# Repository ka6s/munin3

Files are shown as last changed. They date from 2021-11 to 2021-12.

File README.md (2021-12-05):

# munin3
This is a KICAD version of the Munin 3 100W amplifer designed by Kjell - LA2NI. Note that some of the DNI parts have been left out of the schematic. 

The design has been updated to the point that it reliably can balance the two transistors. Haven't verified the
Test Point for that operation yet.

Kjell, LA2NI has reviewed the design and found an error on my part when I did flooding of the power 
transformer.  Kicad didn't really do what I expected. I had to beef up these connections by hand. He also
found a couple errors in my schematic, and I found another later.. these issues have all been 
fixed.

The amplifier seems to work! 

Use the files in gerbers/munin3_v1.1.zip

Steve KA6S

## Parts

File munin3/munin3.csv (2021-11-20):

Reference | Quantity | Identifier | Package | Value | Tolerance | Voltage | Current | Power | PN | Mouser Part Number
L1 | 1 |  |  | Transformer_1P_1S
R8 | 1 |  |  | 100/1W
C8;C15 | 2 |  |  | 1nF
C6;C13;C7;C14 | 4 |  |  | 10nF
R9;R10 | 2 |  |  | 1.5K
R5;R4;R13;R15;R19;R18;R20 | 7 |  |  | 4.7
R7;R6;R12;R11 | 4 |  |  | 22 |  |  |  |  |  | 660-SG73P2ATTD220G
C4;C16 | 2 |  |  | 100pF/500V/NPO |  |  |  |  |  | 603-CC206JRNPOBBN101
L2 | 1 |  |  | Transformer-FB
C12;C11;C10 | 3 |  |  | 220pF/500V/NPO |  |  |  |  |  | 81-GRM31A5C2H221JW1D
L3 | 1 |  |  | Transformer_1P_SS
L4 | 1 |  |  | FT-50-43
C25;C30;C31 | 3 |  |  | 100nF |  |  |  |  |  | 80-C0805C104J5RAUTO
C24;C32 | 2 |  |  | 1uF |  |  |  |  |  | 667-EEE-FT1V561AP
C29;C23 | 2 |  |  | 560uF 35V |  |  |  |  |  | 661-EMZS350ARA561MJA
R23;R24 | 2 |  |  | 0.02 |  |  |  |  |  | 652-CRA2512FZ-R20ELF
U1 | 1 |  |  | MC78L08_SO8 |  |  |  |  |  | 511-L78L08ACD-TR
C35;C34 | 2 |  |  | 1uF |  |  |  |  |  | 80-C0805C104J5RAUTO
C28;C26;C2 | 3 |  |  | 10uF/35V |  |  |  |  |  | GMK316AB7106KL-TR
D6 | 1 |  |  | MBRS2545CT RN |  |  |  |  |  | 821-MBRS2545CTRN
R25 | 1 |  |  | 10K
T3 | 1 |  |  | BSS84 |  |  |  |  |  | 771-BSS84AKVL
J3;J4 | 2 |  |  | Conn_01x02_Male
D5 | 1 |  |  | 1N4001
C27 | 1 |  |  | 0.1uF
L5 | 1 |  |  | FB |  |  |  |  |  | 704-MFBM1V2012-101-R
R1;R22 | 2 |  |  | 2K |  |  |  |  |  | 81-PV12P202A01B00
R2;R21;R26 | 3 |  |  | 1K
C1;C22;C5 | 3 |  |  | 0.1uF |  |  |  |  |  | 0805DD104KAT2A
D1;D4;D2;D3 | 4 |  |  | TS4148 |  |  |  |  |  | 821-TS4148RYG
R3;R17 | 2 |  |  | 22
R16 | 1 |  |  | 3.9K
R14 | 1 |  |  | NTC 10K
C37;C33 | 2 |  |  | 0.01uF |  |  |  |  |  | 80-C0805C103K5TAUTO
R27 | 1 |  |  | 50
U2 | 1 |  |  | LMC6482
T4 | 1 |  |  | BST82 |  |  |  |  |  | 771-BST82235
J2;J1 | 2 |  |  | Conn_Coaxial
T2;T1 | 2 |  |  | Q_NMOS_DSG
H1 | 1 |  |  | +24V
H2 | 1 |  |  | GND

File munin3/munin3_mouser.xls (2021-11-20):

Reference | Quantity | Identifier | Value | Mouser Part Number
L1 | 1 |  | Transformer_1P_1S
R8 | 1 |  | 100/1W | 667-ERJ-12NF1000U
C4;C16 | 2 |  | 100pF/500V/NPO | 603-CC206JRNPOBBN101
C12;C11;C10 | 3 |  | 220pF/500V/NPO | 81-GRM31A5C2H221JW1D
C29;C23 | 2 |  | 560uF 35V | 661-EMZS350ARA561MJA
U1 | 1 |  | MC78L08_SO8 | 511-L78L08ACD-TR
C35;C34 | 2 |  | 1uF | 80-C0805C104J5RAUTO
C28;C26;C2 | 3 |  | 10uF/35V | GMK316AB7106KL-TR
D6 | 1 |  | MBRS2545CT RN | 821-MBRS2545CTRN
T3 | 1 |  | BSS84 | 771-BSS84AKVL
L5 | 1 |  | FB | 704-MFBM1V2012-101-R
R1;R22 | 2 |  | 2K | 81-PV12P202A01B00
C37;C33 | 2 |  | 0.01uF | 80-C0805C103K5TAUTO
U2 | 1 |  | LMC6482 | 511-LMC6482IST
T4 | 1 |  | BST82 | 771-BST82235
J2;J1 | 2 |  | Conn_Coaxial | 712-CONSMA001-C-G

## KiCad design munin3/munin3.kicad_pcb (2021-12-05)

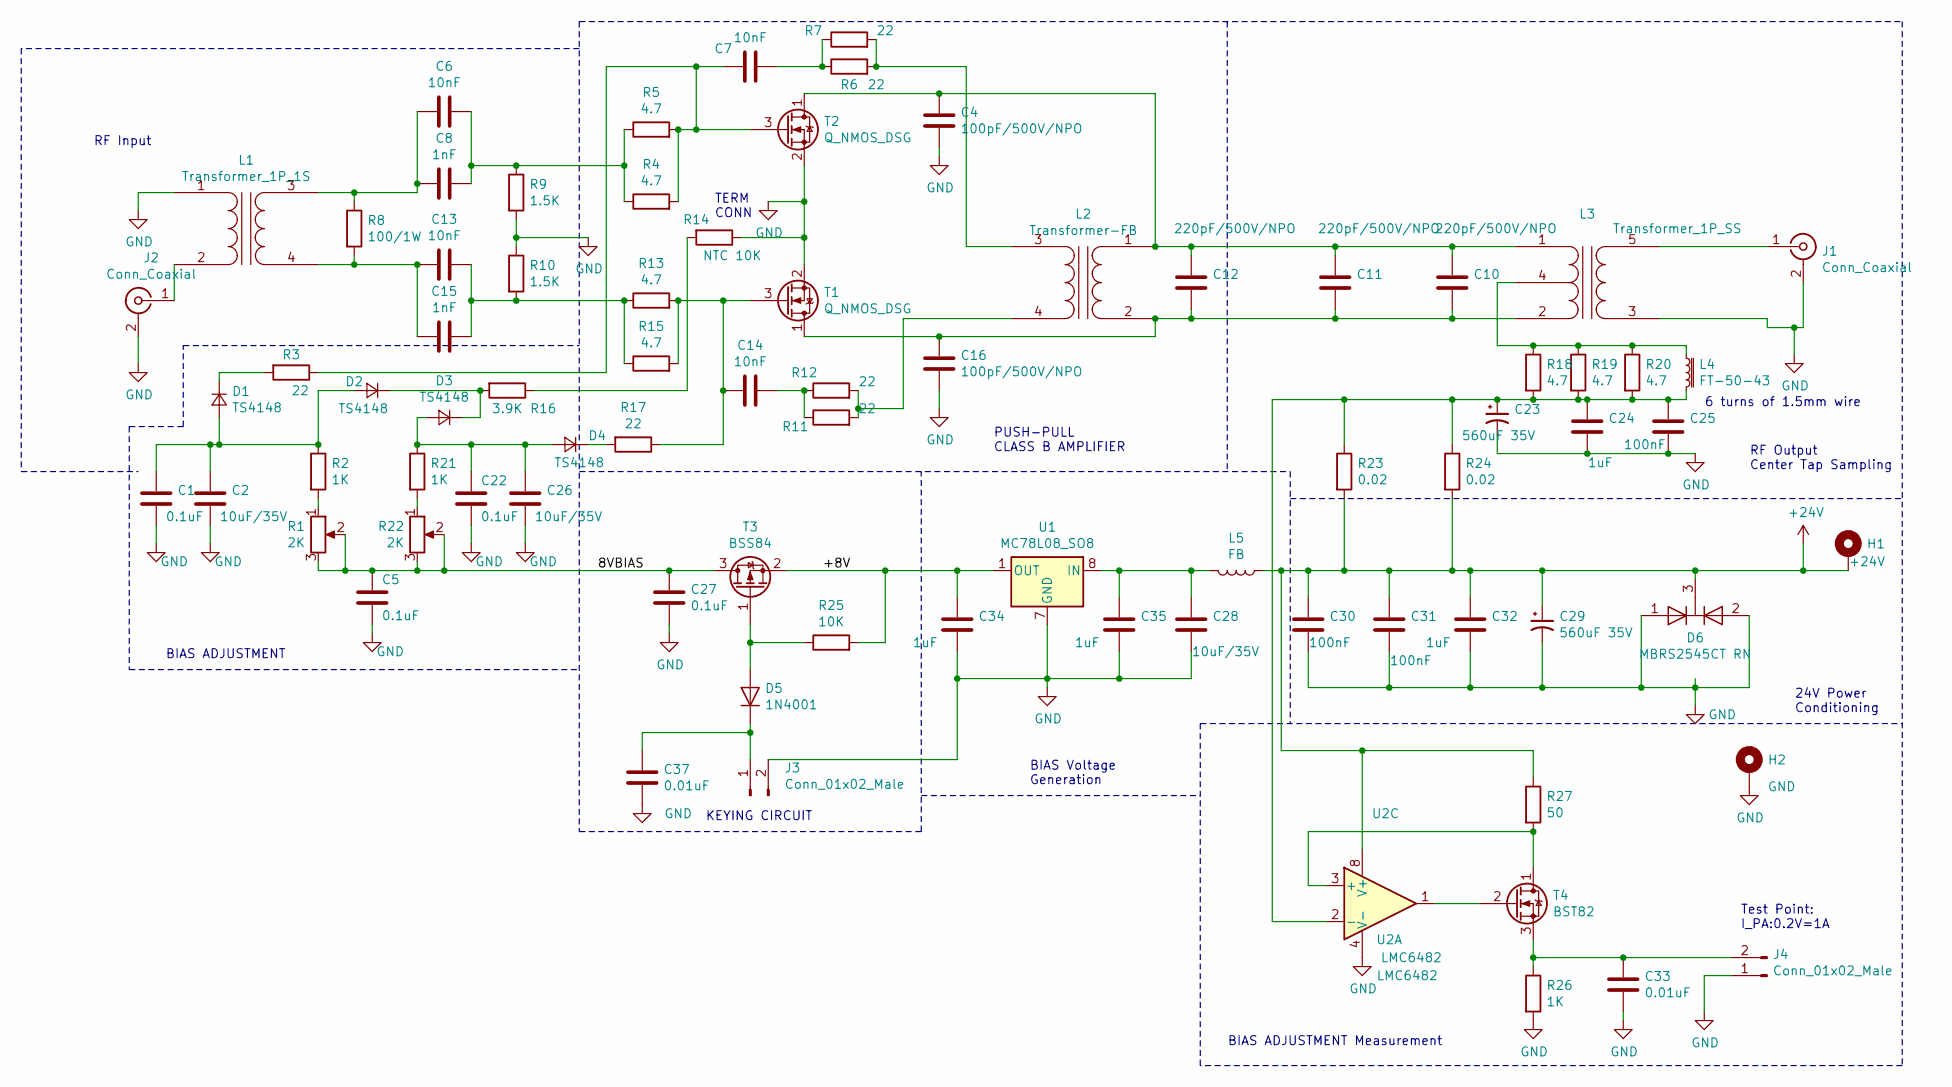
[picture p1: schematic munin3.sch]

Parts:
C1, C5, C22: 0.1uF; C_0805_2012Metric_Pad1.15x1.40mm_HandSolder; Mouser Part Number 0805DD104KAT2A
C2, C26, C28: 10uF/35V; C_1206_3216Metric_Pad1.42x1.75mm_HandSolder; Mouser Part Number GMK316AB7106KL-TR
C4: 100pF/500V/NPO; C_0805_2012Metric_Pad1.15x1.40mm_HandSolder; Mouser Part Number 603-CC206JRNPOBBN101
C6, C7, C13, C14: 10nF; C_0805_2012Metric_Pad1.15x1.40mm_HandSolder
C8, C15: 1nF; C_0805_2012Metric_Pad1.15x1.40mm_HandSolder
C10, C11, C12: 220pF/500V/NPO; C_1206_3216Metric_Pad1.42x1.75mm_HandSolder; Mouser Part Number 81-GRM31A5C2H221JW1D
C16: 100pF/500V/NPO; C_1206_3216Metric_Pad1.42x1.75mm_HandSolder; Mouser Part Number 603-CC206JRNPOBBN101
C23, C29: 560uF 35V; CP_Elec_10x10; Mouser Part Number 661-EMZS350ARA561MJA
C24, C32: 1uF; C_0805_2012Metric_Pad1.15x1.40mm_HandSolder; Mouser Part Number 667-EEE-FT1V561AP
C25, C30, C31: 100nF; C_0805_2012Metric_Pad1.15x1.40mm_HandSolder; Mouser Part Number 80-C0805C104J5RAUTO
C27: 0.1uF; C_0805_2012Metric_Pad1.15x1.40mm_HandSolder
C33, C37: 0.01uF; C_0805_2012Metric_Pad1.15x1.40mm_HandSolder; Mouser Part Number 80-C0805C103K5TAUTO
C34, C35: 1uF; C_0805_2012Metric_Pad1.15x1.40mm_HandSolder; Mouser Part Number 80-C0805C104J5RAUTO
D1, D2, D3, D4: TS4148; D_0805_2012Metric_Pad1.15x1.40mm_HandSolder; Mouser Part Number 821-TS4148RYG
D5: 1N4001; D_0805_2012Metric_Pad1.15x1.40mm_HandSolder
D6: MBRS2545CT RN; TO-263-3_TabPin4; Mouser Part Number 821-MBRS2545CTRN
H1: +24V; MountingHole_11mm_M4_square_Via
H2: GND; MountingHole_11mm_M4_square_Via
J1, J2: Conn_Coaxial; SMA_Amphenol_132291_Vertical
J3, J4: Conn_01x02_Male; PinHeader_1x02_P2.54mm_Vertical
L1: Transformer_1P_1S; RF_Input_XFMR
L2: Transformer-FB; RF_FB_XFMR
L3: Transformer_1P_SS; HF_Power_Xfmr
L4: FT-50-43; RF_Choke
L5: FB; L_MUNIN_FB; Mouser Part Number 704-MFBM1V2012-101-R
R1, R22: 2K; Potentiometer_Bourns_3386P_Vertical; Mouser Part Number 81-PV12P202A01B00
R2, R21, R26: 1K; R_0805_2012Metric_Pad1.15x1.40mm_HandSolder
R3, R17: 22; R_0805_2012Metric_Pad1.15x1.40mm_HandSolder
R4, R5, R13, R15, R18, R19, R20: 4.7; R_0805_2012Metric_Pad1.15x1.40mm_HandSolder
R6, R7, R11, R12: 22; R_0805_2012Metric_Pad1.15x1.40mm_HandSolder; Mouser Part Number 660-SG73P2ATTD220G
R8: 100/1W; R_1812_4532Metric_Pad1.30x3.40mm_HandSolder; Mouser Part Number 667-ERJ-12NF1000U
R9, R10: 1.5K; R_0805_2012Metric_Pad1.15x1.40mm_HandSolder
R14: NTC 10K; R_Axial_DIN0204_L3.6mm_D1.6mm_P2.54mm_Vertical
R16: 3.9K; R_0805_2012Metric_Pad1.15x1.40mm_HandSolder
R23, R24: 0.02; R_2512_6332Metric_Pad1.52x3.35mm_HandSolder; Mouser Part Number 652-CRA2512FZ-R20ELF
R25: 10K; R_0805_2012Metric_Pad1.15x1.40mm_HandSolder
R27: 50; R_0805_2012Metric_Pad1.15x1.40mm_HandSolder
T1, T2: Q_NMOS_DSG; RD100HHF1
T3: BSS84; SOT-23; Mouser Part Number 771-BSS84AKVL
T4: BST82; SOT-23; Mouser Part Number 771-BST82235
U1: MC78L08_SO8; SOIC-8_3.9x4.9mm_P1.27mm; Mouser Part Number 511-L78L08ACD-TR
U2: LMC6482; SOIC-8_3.9x4.9mm_P1.27mm; Mouser Part Number 511-LMC6482IST

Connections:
+24V: C29.1, C30.1, C31.1, C32.1, D6.3 (K), H1.1, L5.1, R23.2, R24.2, R27.1, U2.8 (V+)
/8VBIAS: C5.1, C27.1, R1.2, R1.3, R22.2, R22.3, T3.3 (D)
/+8V: C34.1, R25.2, T3.2 (S), U1.1 (OUT)
GND: C1.2, C2.2, C4.2, C5.2, C16.2, C22.2, C23.2, C24.2, C25.2, C26.2, C27.2, C28.2, C29.2, C30.2, C31.2, C32.2, C33.2, C34.2, C35.2, C37.2, D6.1 (A), D6.2 (A), H2.1, J1.2 (Ext), J2.2 (Ext), J3.2, J4.1, L1.1 (AA), L3.3 (AB), R9.2, R10.1, R14.1, R26.2, T1.2 (S), T2.2 (S), U1.2 (GND), U1.3 (GND), U1.6 (GND), U1.7 (GND), U2.4 (V-)
unnamed: C1.1, C2.1, D1.2 (A), D2.2 (A), R2.1
unnamed: C6.1, C8.1, R4.1, R5.1, R9.1
unnamed: C6.2, C8.2, L1.3 (SB), R8.1
unnamed: C7.1, R6.1, R7.1
unnamed: C7.2, R3.1, R4.2, R5.2, T2.3 (G)
unnamed: C4.1, C10.1, C11.1, C12.1, L2.1 (AA), L3.1 (SB), T2.1 (D)
unnamed: C10.2, C11.2, C12.2, C16.1, L2.2 (AB), L3.2 (SA), T1.1 (D)
unnamed: C13.1, C15.1, R10.2, R13.1, R15.1
unnamed: C13.2, C15.2, L1.4 (SA), R8.2
unnamed: C14.1, R11.1, R12.1
unnamed: C14.2, R13.2, R15.2, R17.1, T1.3 (G)
unnamed: C22.1, C26.1, D3.2 (A), D4.2 (A), R21.1
unnamed: C23.1, C24.1, C25.1, L4.2, R18.2, R19.2, R20.2, R23.1, R24.1, U2.2 (-)
unnamed: C28.1, C35.1, L5.2, U1.8 (IN)
unnamed: C33.1, J4.2, R26.1, T4.3 (S)
unnamed: C37.1, D5.1 (K), J3.1
unnamed: D1.1 (K), R3.2
unnamed: D2.1 (K), D3.1 (K), R16.2
unnamed: D4.1 (K), R17.2
unnamed: D5.2 (A), R25.1, T3.1 (G)
unnamed: J1.1 (In), L3.5 (AA)
unnamed: J2.1 (In), L1.2 (AB)
unnamed: L2.3 (SB), R6.2, R7.2
unnamed: L2.4 (SA), R11.2, R12.2
unnamed: L3.4 (SC), L4.1, R18.1, R19.1, R20.1
unnamed: R1.1, R2.2
unnamed: R14.2, R16.1
unnamed: R21.2, R22.1
unnamed: R27.2, T4.1 (D), U2.3 (+)
unnamed: T4.2 (G), U2.1

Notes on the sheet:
6 turns of 1.5mm wire
KEYING CIRCUIT
PUSH-PULL CLASS B AMPLIFIER
BIAS ADJUSTMENT
TERM CONN
Test Point: I_PA:0.2V=1A
BIAS ADJUSTMENT Measurement
24V Power Conditioning
BIAS Voltage Generation
RF Output Center Tap Sampling
RF Input

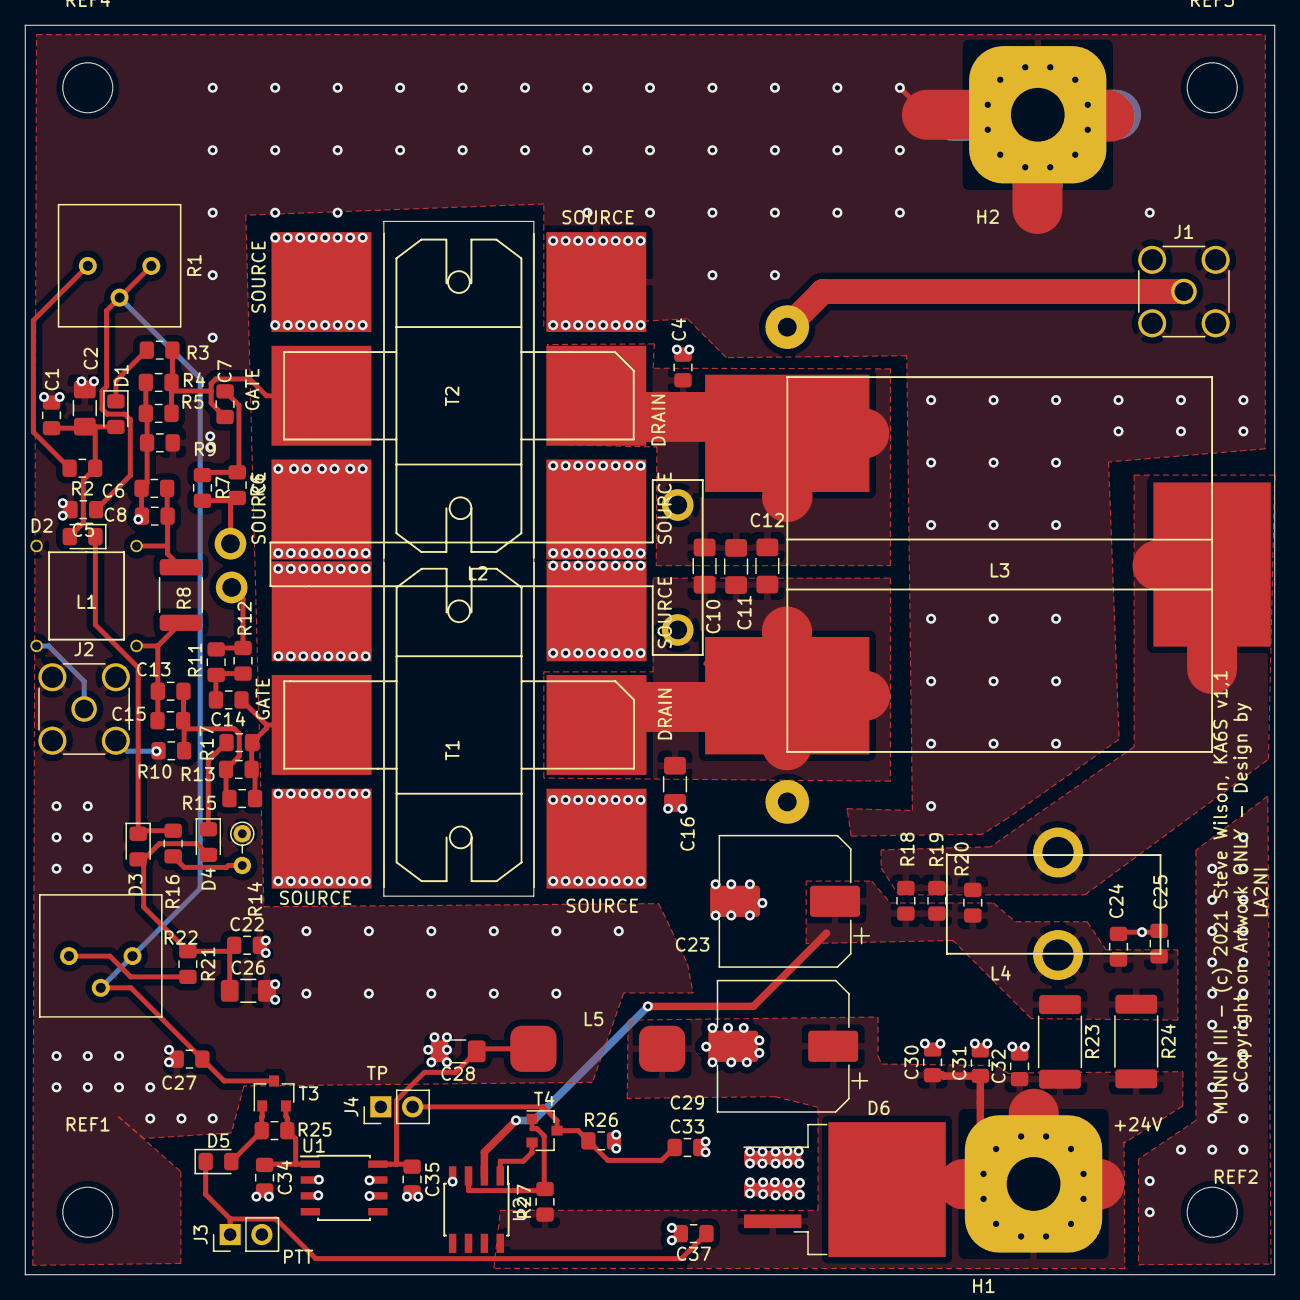
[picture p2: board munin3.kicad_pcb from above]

Board: 2 copper layers, 100.0 x 100.0 mm, 83 parts (0 on the bottom side), 34 nets.

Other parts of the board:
REF1, REF2, REF3, REF4: MountingHole_6mm

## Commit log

2021-12-04 Fixed drain connection, fixed final xfmr connection
    [munin3.kicad_pcb, munin3.sch]
2021-12-05 Removed short between C8 and C15 on schem. Beefed up power/ground/Power Xfmr connections.
    [munin3.kicad_pcb, munin3.sch]
2021-12-05 Updated Version Number
    [munin3.kicad_pcb]
2021-12-05 New Gerbers with fixes
    [munin3-B_Cu.gbl, munin3-B_Mask.gbs, munin3-B_Paste.gbp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]
2021-12-05 Remove older gerber zip

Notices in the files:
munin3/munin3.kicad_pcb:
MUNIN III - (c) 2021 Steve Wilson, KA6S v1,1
